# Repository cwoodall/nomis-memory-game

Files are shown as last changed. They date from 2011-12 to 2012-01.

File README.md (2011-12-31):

# Nomis Memory Game V01

A Simon-like Memory Game for the ATTiny85 (+ some electronics)!

2011 (c) Christopher Woodall
MIT License

## Overview

Nomis is a Simon-like Memory game for the ATTiny85 (+ some electronics). The 
goal of the game is to copy the random string of moves that the 
microcontroller, makes. If you make a wrong move you go back to the IDLE state
(the lights cascade). After you copy the string so far, the computer will
display the string again and then add an extra move. The process repeats,
until you mess up. The goal of the game is not to win (since there are no
real winning conditions), the goal is to beat your previous score and 
"improve your memory".

## Layout

nomis-memory-game.c: This is the main game file, which controls the game logic.

scripts/lcg.py: A little test of the Linear Congruential Generator, which I 
used to generate random numbers

scripts/lfsr.py: A little test of a Linear Feedback Shift Register, which was
another option for my random number generator

schematics/nomis-memory-game-v01.sch: EAGLE schematic for the game

##

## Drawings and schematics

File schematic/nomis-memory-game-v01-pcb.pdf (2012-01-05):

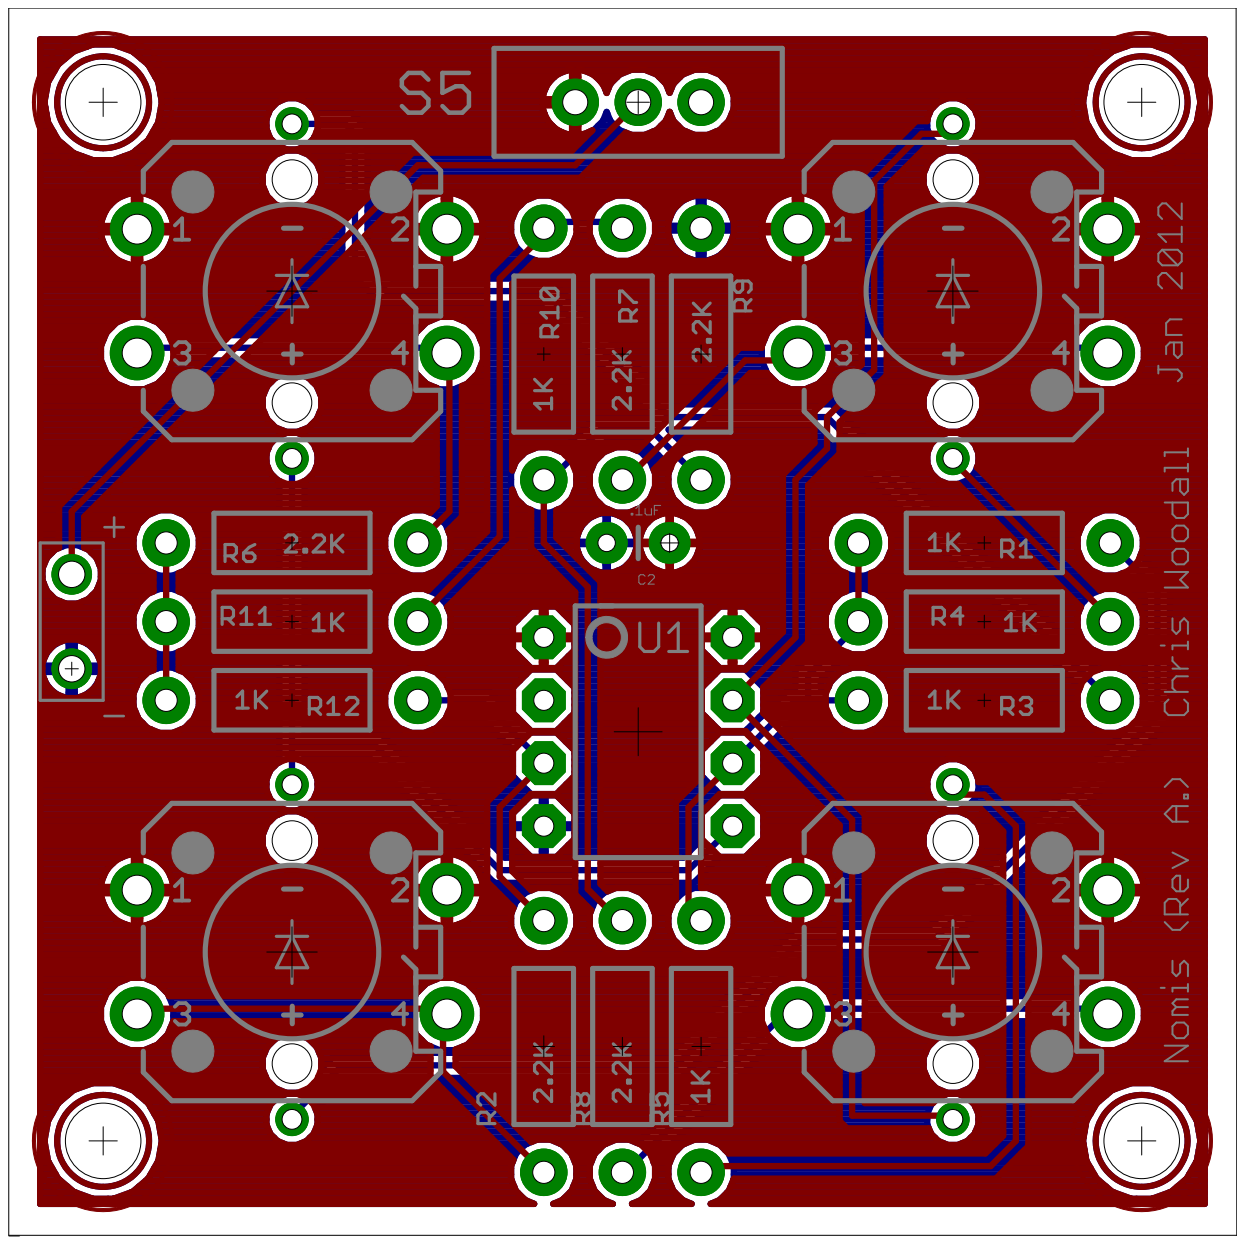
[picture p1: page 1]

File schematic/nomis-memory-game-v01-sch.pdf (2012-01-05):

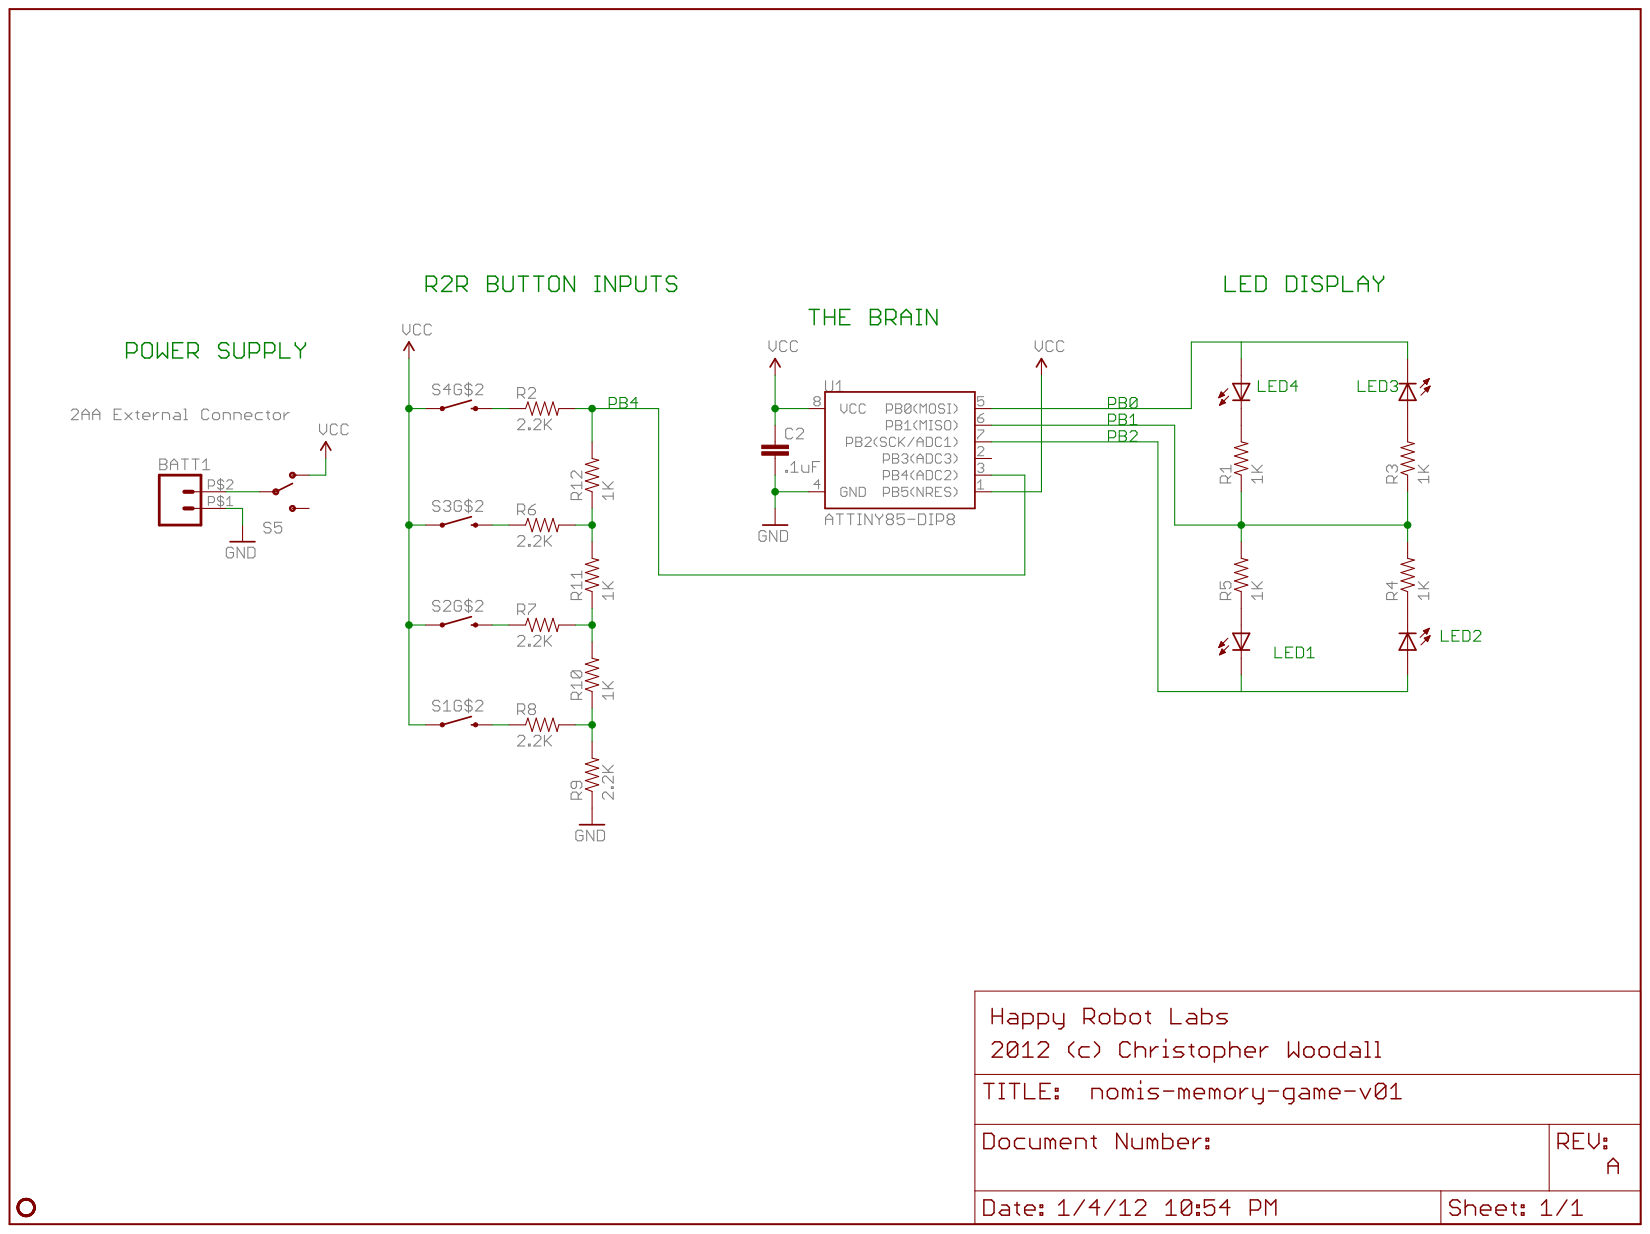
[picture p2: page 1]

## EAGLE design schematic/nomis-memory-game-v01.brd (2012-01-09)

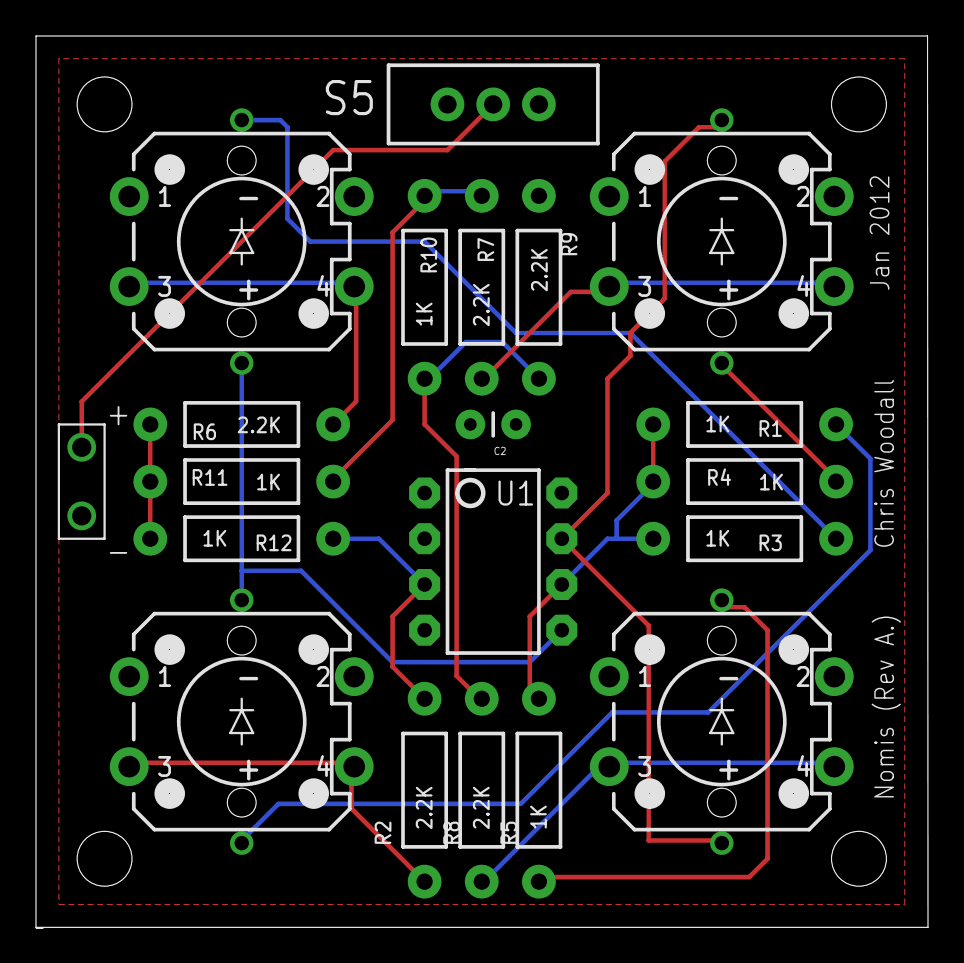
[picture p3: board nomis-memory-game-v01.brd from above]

Board: 2 copper layers, 49.6 x 49.5 mm, 24 parts (0 on the bottom side), 18 nets.

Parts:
BATT1: 2AA External Connector; 1X02_BIG
C2: .1uF; CAP-PTH-SMALL
JP1, JP2, JP3, JP4: STAND-OFFTIGHT; STAND-OFF-TIGHT
R1, R3, R4, R5, R10, R11, R12: 1K; AXIAL-0.4
R2, R6, R7, R8, R9: 2.2K; AXIAL-0.4
S1, S2, S3, S4: SWITCH-MOMENTARY-LED-SPLIT; TACTILE-PTH-LED-12MM
S5: SWITCH-SPDT
U1: ATTINY85-DIP8; DIP08

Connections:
GND: BATT1.P$1, C2.2, R9.P$1, U1.4
unnamed: R3.P$2, S3.A
unnamed: R4.P$1, S2.C
unnamed: R5.P$1, S1.A
unnamed: R1.P$2, S4.C
unnamed: R1.P$1, R3.P$1, R4.P$2, R5.P$2, U1.6
unnamed: S1.C, S2.A, U1.7
unnamed: S3.C, S4.A, U1.5
unnamed: R8.P$2, R9.P$2, R10.P$1
unnamed: R7.P$2, R10.P$2, R11.P$1
unnamed: BATT1.P$2, S5.2
unnamed: R2.P$2, R12.P$2, U1.3
unnamed: R2.P$1, S4.3, S4.4
unnamed: R6.P$1, S3.3, S3.4
unnamed: R7.P$1, S2.3, S2.4
unnamed: R8.P$1, S1.3, S1.4
unnamed: R6.P$2, R11.P$2, R12.P$1
VCC: C2.1, S1.1, S1.2, S2.1, S2.2, S3.1, S3.2, S4.1, S4.2, S5.1, U1.1, U1.8

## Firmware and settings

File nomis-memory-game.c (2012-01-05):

/**
 * Project: Memory Game
 * Version: 01
 * Creator(s): Christopher Woodall
 * License: MIT License
 * 
 * Memory Game is a Simon (tm) clone based around an ATTiny85 microprocessor.
 * The game generates a "random" string of moves for the player to copy.
 * If the player is unable to remember the string and presses a wrong button,
 * then the game is over and the player looses.
 *
 * The random numbers are generated using a Linear Congruential Generator (LCG),
 * which functions based on the formula X_next = (a*X_n + c) mod m. The 
 * selection of a, c and m are very important for generating a series of
 * psuedo-random numbers with the maximum period of m. Selection is outlined
 * inside of the rand_lcg() function
 */
#define F_CPU 1000000 /* 1MHz Internal Oscillator */

#include <avr/io.h>
#include <util/delay.h>
#include <avr/eeprom.h>
#include <avr/interrupt.h>

#define MAX_PERIOD 32768 // 2^15
#define MULTIPLIER 513   // 2^9 + 1 (A-1 is divisible by all prime factors of M)
#define C          1     // We know 1 is relatively prime with M
#define MAX_MOVES  100   // Maximum number of moves

#define clear_display() PORTB &= 0xF0;
#define set_display(state) PORTB |= led_display(state);

/**
 * enum STATE gamestates: IDLE, CPU, PLAYER, LOSE
 *  
 * \breif Define state names for the finite state machine that runs the game flow.
 *         
 * IDLE: The MCU waits for an input from the user to play the game. In this state
 *       the MCU cascades the LEDS, signifying that it is on and ready to go. While
 *       this is happening the MCU is incrementing the random variable to
 *       continuously change the seed. Exits into the CPU state if a button is
 *       pressed.
 *
 * CPU: The CPU's turn. The CPU (well MCU) generates a random number and,
 *        adds that as a move to the moves[] array. Then the CPU returns the game
 *        to the PLAYER state. Ignores input from player.
 * 
 * PLAYER: The player's turn, in this state the MCU will wait for a string of 
 *           inputs from the player. Once the Player presses a button that is not
 *           in the array moves[], the player looses the game and the game goes to
 *           the LOSE state. Otherwise the game goes to the CPU state and the 
 *           computer adds another move to the moves array.
 *
 * LOSE: Cleans up the game and returns to the IDLE state. Just for house keeping.
 */
enum STATE {
    IDLE,
    CPU,
    PLAYER,
    LOSE,
} gamestates;

/** Function Headers */
uint16_t read_adc();
uint8_t led_display(uint8_t state);
uint16_t rand_lcg(uint16_t lcg_previous, uint16_t m, uint16_t a, uint16_t c);
void cascade_leds();
void blink_leds();
uint8_t get_player_move();

enum STATE gamestate = IDLE;

int main (void)
{
    /**
     * \var  uint8_t   moves  tracks the computers moves which the player 
     *                          must match.
     *
     * \var  uint8_t   player_moves  tracks the players moves, gets reset after 
     *                                 every turn.
     *
     * \var  uint16_t  i  predefine looping variable for future loops
     * 
     * \var  uint16_t  counter  Generic counting variable, used to count the number
     *                            of moves the computer has made, and the player 
     *                            has made.
     *
     * \var  uint16_t  random  Seed random with whatever junk is in the eeprom 
     *                           region at 46. We store future random generations
     *                           there to be used as future seeds, on future 
     *                           bootup or resets.
     *
     * \var  STATE  gamestate  Keep track of where the game is. 4 possible states,
     *                           IDLE (0), CPU (1), PLAYER (2), or LOSE (4).
     */
    uint8_t moves[MAX_MOVES]; 
    uint16_t i; 
    uint16_t cpu_counter = 0; 
    uint16_t player_counter = 0;
    uint16_t random = eeprom_read_word((uint16_t *) 46);
    uint16_t player_move;
    //    enum STATE gamestate = CPU;
    // Set up PortB pins 0, 1, and 2 to be outputs.
    DDRB = 0x07;
    // Set pull down resistors and all pins off.
    PORTB = 0x00;
   
    // Setup the ADC

    // Select ADC2
    ADMUX = 0b00000010; 
    // ADCSRA[7]: Set ADEN on.
    // ADCSRA[2:0]: Set to 011 for a divide by 8 clock division. 
    //                (125 kHz ADC clock)
    ADCSRA = 0b10000011;

    // And now the games begin!
    while (1) {
        if (gamestate == CPU) {
            // Get a new random number from the lcg
            random = rand_lcg(random, MAX_PERIOD, MULTIPLIER, C ); 
            eeprom_write_word((uint16_t *)46, random); // Store last random value in the EEPROM for next seed, if reset occurs
            // Store this move into memory. First shift rand over and only take the
            // two most significant bits.
            moves[cpu_counter] = 0x01 << (random >> 13);
            
            for (i = 0; i <= cpu_counter; i++) {
                // Translate the move into something that we can send to the 
                // charlieplexed LEDs
                PORTB |= led_display(moves[i]); 
                _delay_ms(500);
                PORTB &= 0xF0;
                _delay_ms(100);
            }
            cpu_counter += 1;
            gamestate = PLAYER;
            _delay_ms(10);
        } else if (gamestate == PLAYER) {
            player_move = get_player_move(); 
            if (player_move == 0) {
                clear_display();
            } else {
                set_display(player_move);               
                _delay_ms(50);
                clear_display();
                _delay_ms(50);
                set_display(player_move);
                _delay_ms(50);
                clear_display();
                if (player_move == moves[player_counter]) {
                    if (player_counter == (cpu_counter-1)) {
                        player_counter = 0;
                        _delay_ms(1000);
                        gamestate = CPU;
                    } else {   
                        player_counter += 1;
                    }
                } else {
                    player_counter = 0;
                    cpu_counter = 0;
                    
                    gamestate = IDLE;
                    blink_leds();
                    _delay_ms(100);
                    blink_leds();
                    _delay_ms(500);

                }
            }
        } else if (gamestate == IDLE) {
            // When the game is IDLE (not being played), increment the seed.
            // Once random is done being incremented store that value at location
            // 46 in the EEPROM so it can be accessed later.
            random += 0x0001;
            eeprom_write_word((uint16_t *)46, random);
            cascade_leds();
            if (read_adc() > 200) {
                gamestate = CPU;
                blink_leds();
                _delay_ms(100);
                blink_leds();
                _delay_ms(500);
            }
        } else {
            // Flash LED 1 and 4 if there is an error
            PORTB |= led_display(0x01);
            _delay_ms(100);
            PORTB &= 0xF0;
            _delay_ms(100);
            PORTB |= led_display(0x08);
            _delay_ms(100);
            PORTB &= 0xF0;
            _delay_ms(100);
        }
    }
    return 0;
}


/**
 * led_display()
 * \param   uint8_t  state  The 4-bit one hot encoding of the current game move.
 * \return  uint8_t  encoded_state  The encodign for our charlieplexed LED display.
 *
 * \breif Converts a 4-but one hot encoded gamestate into an encoding appropriate for 
 *        the charlieplexed LED display on PORTB pins 0, 1 and 2.
 *
 * LEDS, MUST be on pins 0, 1 and 2 on any PORT. However, this can be changed by
 * changing the encodings.
 */
uint8_t led_display(uint8_t state)
{
    switch (state) {
    case 0x01:
        return 0x03;
        break;
    case 0x02:
        return 0x04;
        break;
    case 0x04:
        return 0x06;
        break;
    case 0x08:
        return 0x01;
        break;
    default:
        return 0x00;
        break;
    }
}

/**
 * cascade_leds()
 * 
 *
 * \brief Cascade the output LEDs on and off using POV.
 *        Used for the idle gamestate.
 */
void cascade_leds()
{
    /// Predefinition of the for loop variable... Saves memory
    static uint16_t i = 0;
    static uint8_t up = 1;
   
    PORTB |= led_display(0x01 << i);
    _delay_ms(100);
    PORTB &= 0xF0;
    _delay_ms(50);

    if (i == 3)
        up = 0;
    else if (i == 0)
        up = 1;

    if (up)
        i += 1;
    else
        i -= 1;
}

void blink_leds() {
    uint16_t j;
    uint16_t i;
    for( i = 0; i < 100; i++) {
        for (j = 0; j <= 3; j++) {
            set_display(0x01 << j);
            _delay_us(100);
            clear_display();
            _delay_us(10);
        }
    }
}

// rand_lcg generates a random number from some set of parameters, where the result
// is constantly fedback into the function when a new random number is desired. 
// Needs some initial seed value.
//
// m, a and c need to be chosen carefully
uint16_t rand_lcg(uint16_t lcg_previous, uint16_t m, uint16_t a, uint16_t c)
{
    return (lcg_previous*a + c) % m;
}

uint16_t read_adc() {
    // TODO: Make more general and allow channel selection

    // ADCSRA[6]: start single conversion
    ADCSRA |= 0b01000000;
    
    // Loop until ADIF interrupt occurs
    while(!(ADCSRA & (1 << ADIF)));
    
    // Clear ADIF by writing 1 to it
    ADCSRA |= (1<<ADIF);

    // Return the ADC data
    return ADC;
}


uint8_t get_player_move() {
    uint16_t raw_move = read_adc();
    uint8_t move;
    static uint8_t prev_move = 0;
    if ((raw_move >= 500) & (raw_move <= 520)) {
        move = 0x01;
    } else if ((raw_move >= 600) & (raw_move <= 620)) {
        move = 0x02;
    } else if ((raw_move >= 660) & (raw_move <= 680)) {
        move = 0x04;
    } else if ((raw_move >= 710) & (raw_move <= 730)) {
        move = 0x08;
    } else {
        move = 0x00;
    }
    
    // Make the reading edge sensitive
    if (move == prev_move)
        move = 0;
    else
        prev_move = move;
    
    // Try to prevent bouncing
    _delay_us(1000);
    return move;
}

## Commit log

2011-12-31 Edited README.md and started Schematic
    [nomis-memory-game-v01.sch]
2011-12-31 Added Schematic File
    [nomis-memory-game-v01.sch]
2012-01-02 Added PCB board layout and edited the schematic a bit to fit the PCB board. Need to clean up a few things yet
    [nomis-memory-game-v01.GBL, nomis-memory-game-v01.GBO, nomis-memory-game-v01.GBP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]
2012-01-05 Fixed schematic inconsistencies and PCB... Too bad I ordered the boards already. Trying to fix that
    [nomis-memory-game-v01.GBL, nomis-memory-game-v01.GBO, nomis-memory-game-v01.GBP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]
2012-01-09 fixed up schematics and revised code a bit. Nothing major
    [nomis-memory-game-v01.brd]
2012-01-09 Updated pcb gerber files. Review PCB once more before sending out to Seeed again (first run had a major error in it :/)
    [nomis-memory-game-v01.GBL, nomis-memory-game-v01.GBO, nomis-memory-game-v01.GBS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]

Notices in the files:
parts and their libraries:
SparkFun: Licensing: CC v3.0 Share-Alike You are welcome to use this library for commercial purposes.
